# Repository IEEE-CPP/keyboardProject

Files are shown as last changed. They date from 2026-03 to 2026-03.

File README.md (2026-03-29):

# Split Keyboard

A custom split ergonomic keyboard designed with Ergogen and KiCad.

## Keyboard Layout

- **5-column layout**: outer, pinky, ring, middle, index, inner
- **5 rows**: mod, bottom, home, top, num
- **3-thumb keys**: layer, space, extra
- **Column-based wiring** with row diodes

### Features

- Choc hotswap sockets (Kailh Choc low-profile switches)
- Pro Micro microcontroller (ATmega32U4)
- OLED displays (SSD1306, I2C)
- TRRS jack for inter-board communication
- ESD protection on TRRS data lines
- Reset button
- 3D printable case files (STL)

## Files

```
splitKeyboard/
├── ergogen/
│   ├── config.yaml    # Ergogen configuration (layout, PCB definitions)
│   ├── footprints/    # Custom footprint definitions
│   └── output/
│       ├── cases/    # 3D printable case files (STL)
│       └── outlines/ # DXF files for CNC cutting
└── kicad/
    ├── left_board.kicad_pcb   # Left half PCB design
    └── right_board.kicad_pcb  # Right half PCB design
```

## Development Setup

### Manual (recommended)

Install ergogen from https://ergogen.xyz/install/, then generate PCBs:

```bash
ergogen splitKeyboard/ergogen/ --output build/
```

### Nix (optional)

For users with Nix installed:

```bash
nix develop    # provides kicad + ergogen
generate       # runs ergogen (PCB + cases) and organizes output
```

## Design Details

- **Microcontroller**: Pro Micro (5V, 16MHz)
- **Key switches**: Kailh Choc (low-profile)
- **Diodes**: 1N4148 (or similar)
- **OLED**: SSD1306 128x32 I2C
- **Interconnect**: TRRS cable (4-pole)
- **ESD Protection**: TVS diodes (PRTR5V0U2X or similar)

### Pin Mapping

| Column | Pin |
| --- | --- |
| outer  | P21 |
| pinky  | P20 |
| ring | P19 |
| middle | P18 |
| index  | P15 |
| inner  | P14 |
| thumb  | P16 |
| space  | P10 |
| extra  | P9  |

| Row | Pin |
| --- | --- |
| mod | P8  |
| bottom | P7  |
| home | P6  |
| top | P5  |
| num | P4  |

### OLED

- SDA: P2
- SCL: P3

## Building

1. Generate PCB files (see Development Setup above)

2. Open `splitKeyboard/kicad/` in KiCad to generate Gerbers

3. Order PCBs from your preferred manufacturer

4. Solder components:
   - Diodes (observe polarity)
   - Hotswap sockets
   - TRRS jack
   - Reset button
   - OLED display
   - Pro Micro header pins (or socket)

5. Flash firmware using QMK or ZMK

## Firmware

This repository only contains the hardware design. For firmware, use:

- **QMK**: https://github.com/qmk/qmk_firmware
- **ZMK**: https://github.com/zmkfirmware/zmk

## License

GNU General Public License v3. See [LICENSE](LICENSE) for details.

## Credits

- [Ergogen](https://github.com/ergogen/ergogen) - Keyboard layout generator
- [KiCad](https://www.kicad.org/) - PCB design software

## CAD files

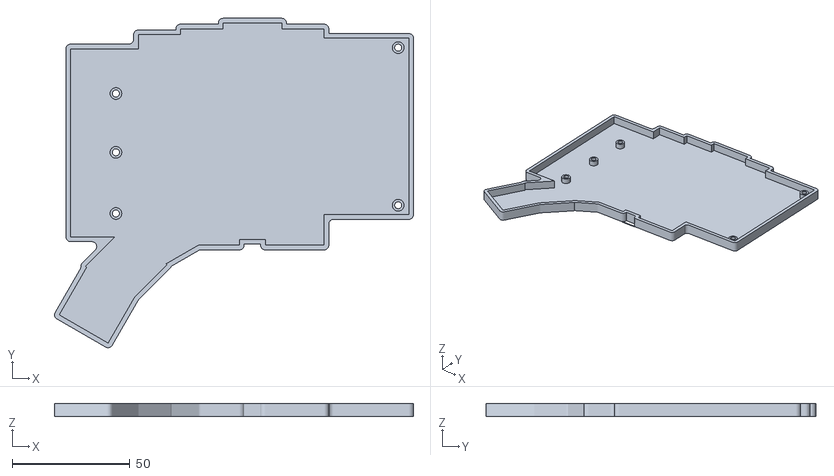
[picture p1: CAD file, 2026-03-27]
splitKeyboard/ergogen/output/cases/right_case.stl
152.6 x 140.1 x 5.60

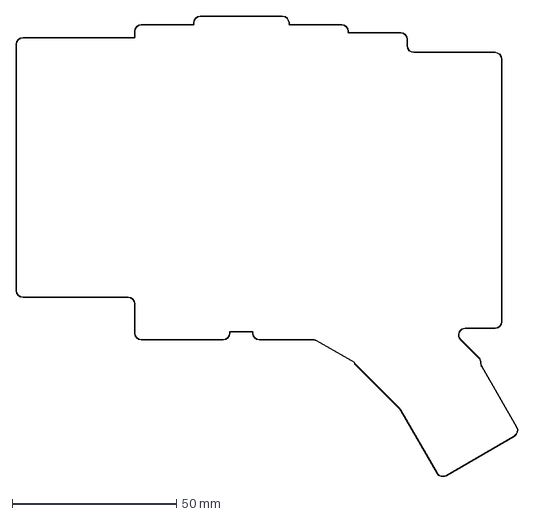
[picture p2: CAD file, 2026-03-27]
splitKeyboard/ergogen/output/outlines/left_xl.dxf
152.9 x 140.2 mm

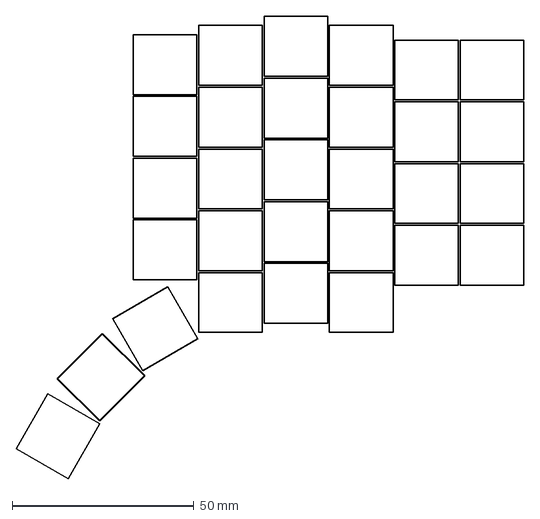
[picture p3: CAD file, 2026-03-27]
splitKeyboard/ergogen/output/outlines/right_keys.dxf
139.7 x 127.2 mm

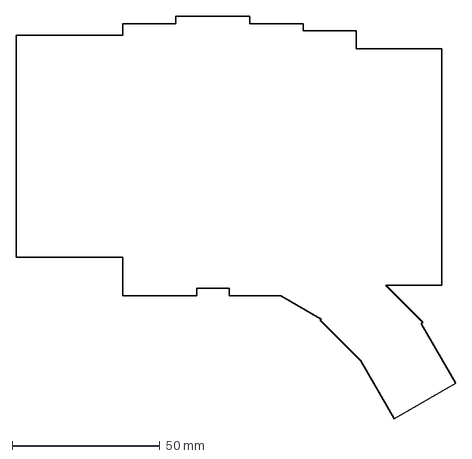
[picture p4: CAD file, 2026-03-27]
splitKeyboard/ergogen/output/outlines/left_raw.dxf
148.6 x 136.1 mm

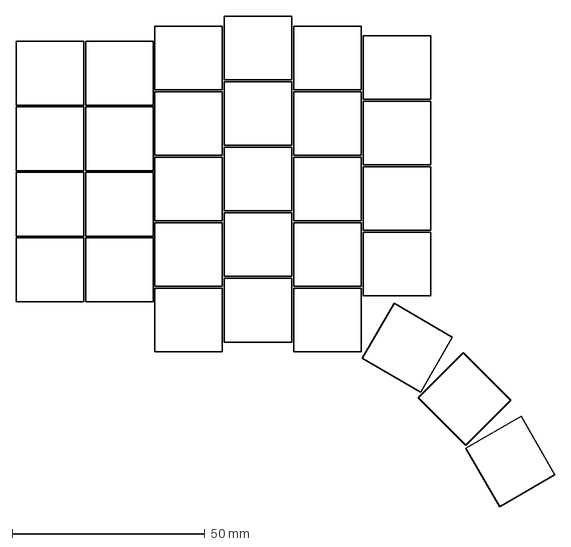
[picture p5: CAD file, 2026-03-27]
splitKeyboard/ergogen/output/outlines/left_keys.dxf
139.7 x 127.2 mm

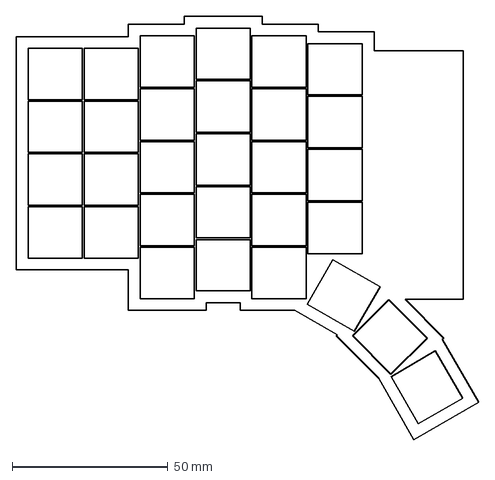
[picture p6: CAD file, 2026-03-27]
splitKeyboard/ergogen/output/outlines/combo_left.dxf
148.6 x 136.1 mm

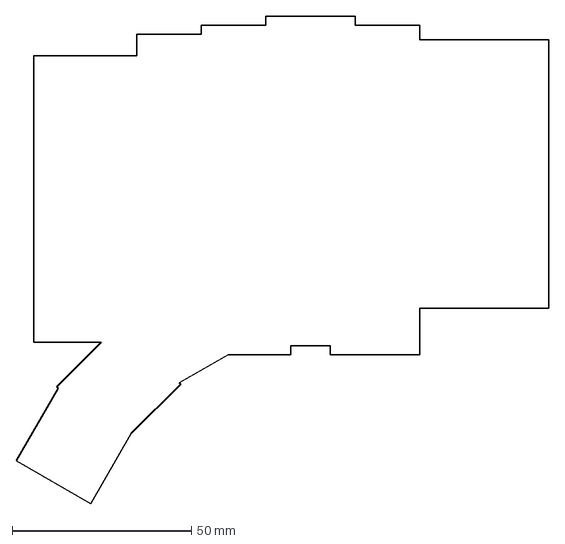
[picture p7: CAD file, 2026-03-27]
splitKeyboard/ergogen/output/outlines/right_raw.dxf
148.6 x 136.1 mm

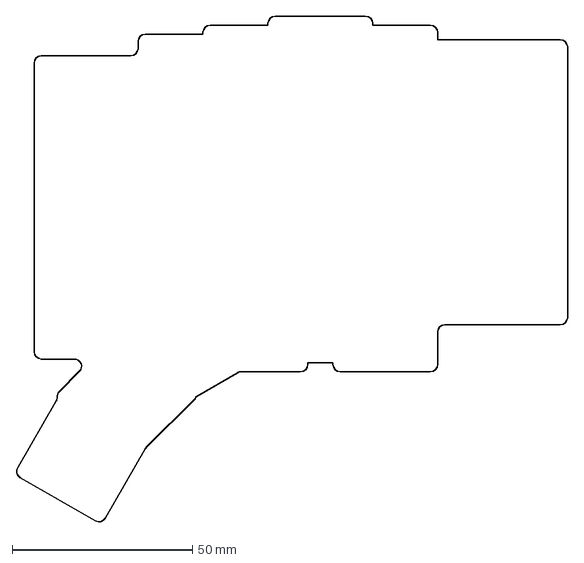
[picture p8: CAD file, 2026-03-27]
splitKeyboard/ergogen/output/outlines/right_xl.dxf
152.7 x 140.4 mm

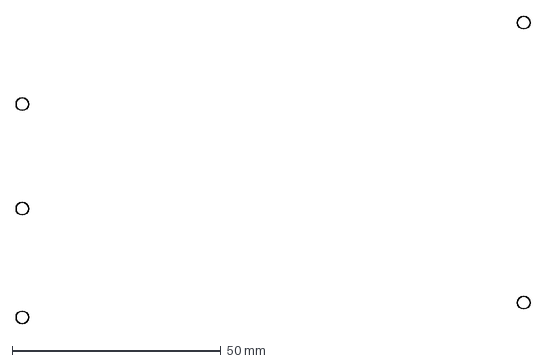
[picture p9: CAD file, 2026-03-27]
splitKeyboard/ergogen/output/outlines/right_mounting.dxf
123.0 x 73.5 mm

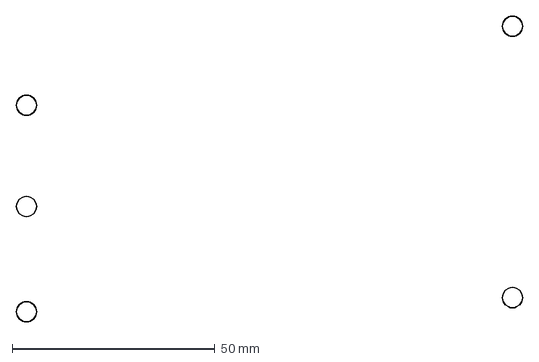
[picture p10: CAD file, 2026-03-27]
splitKeyboard/ergogen/output/outlines/right_standoff.dxf
125.0 x 75.5 mm

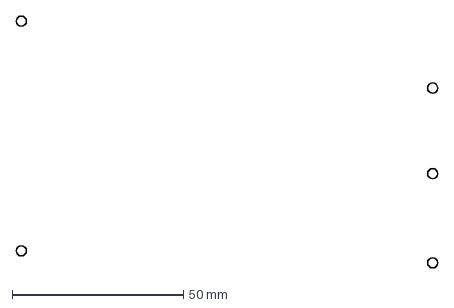
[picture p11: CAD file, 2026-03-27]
splitKeyboard/ergogen/output/outlines/left_mounting.dxf
123.0 x 73.5 mm

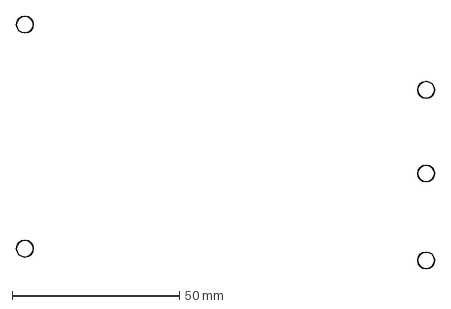
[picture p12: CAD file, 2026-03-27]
splitKeyboard/ergogen/output/outlines/left_standoff.dxf
125.0 x 75.5 mm

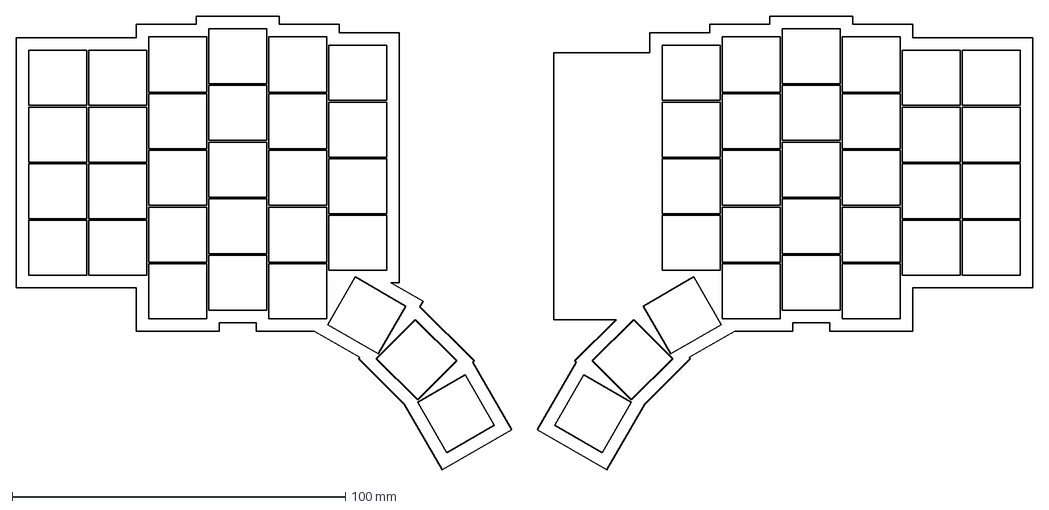
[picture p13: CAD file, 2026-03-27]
splitKeyboard/ergogen/output/outlines/combo_right.dxf
305.0 x 136.1 mm

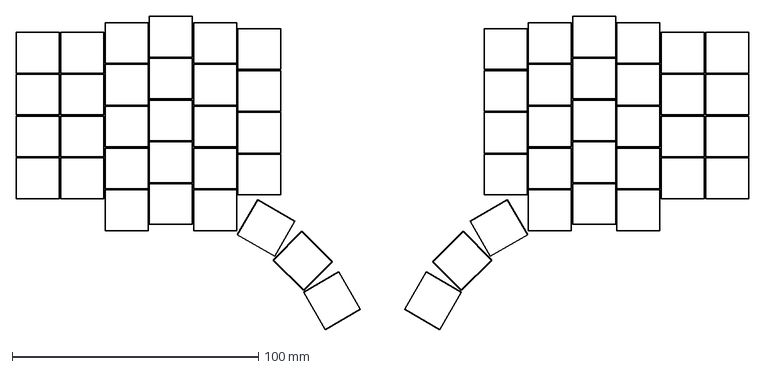
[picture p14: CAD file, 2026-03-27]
splitKeyboard/ergogen/output/outlines/keys.dxf
297.5 x 127.2 mm

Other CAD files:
splitKeyboard/ergogen/output/cases/left_case.stl

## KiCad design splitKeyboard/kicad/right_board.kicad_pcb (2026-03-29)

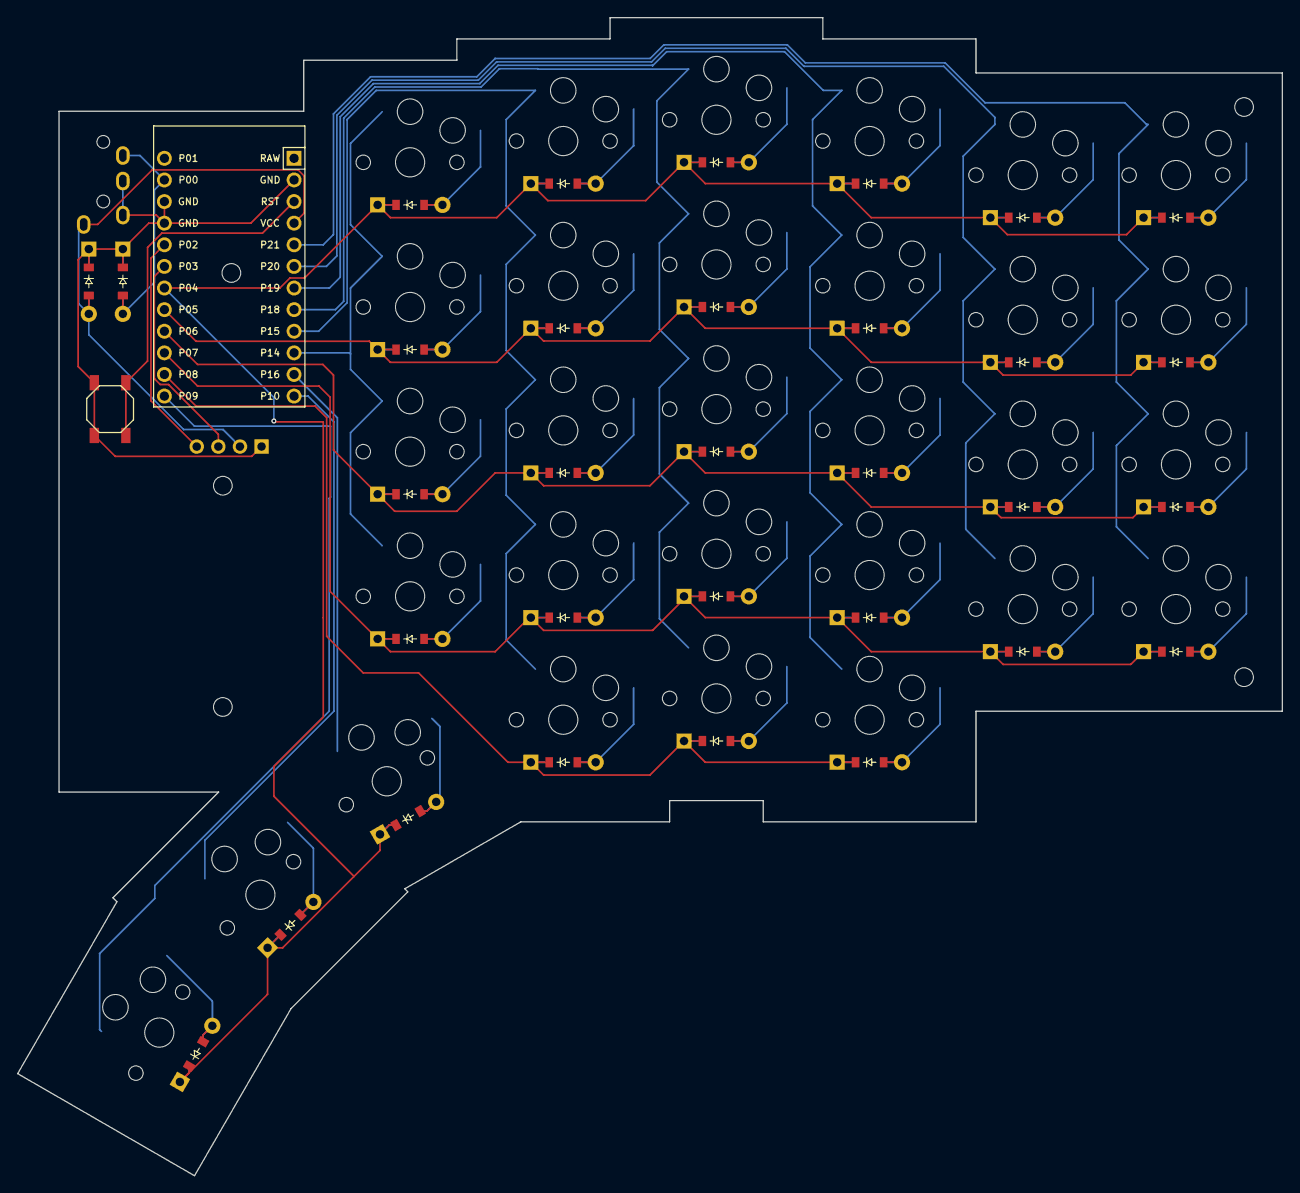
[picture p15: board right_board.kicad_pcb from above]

Board: 2 copper layers, 148.6 x 136.1 mm, 71 parts (0 on the bottom side), 50 nets.

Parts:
B1: SW_TACT_ALPS_SKQGABE010
D1, D2, D3, D4, D5, D6, D7, D8, D9, D10, D11, D12, D13, D14, D15, D16, D17, D18, D19, D20, D21, D22, D23, D24, D25, D26, D27, D28, D29, D30, D31, D32: ComboDiode
MCU1: ProMicro
MH1, MH2, MH3, MH4, MH5: mounting_hole_npth
OLED1: OLED; OLED_headers
S1, S2, S3, S4, S5, S6, S7, S8, S9, S10, S11, S12, S13, S14, S15, S16, S17, S18, S19, S20, S21, S22, S23, S24, S25, S26, S27, S28, S29, S30: PG1350
TRRS1: TRRS-PJ-320A-dual

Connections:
GND: B1.1, D31.1, D32.1, MCU1.2, MCU1.15, MCU1.16, OLED1.1, TRRS1.2, TRRS1.3
P0: D31.2, MCU1.14, TRRS1.4
P2: MCU1.17, OLED1.4
P3: MCU1.18, OLED1.3
P4: D4.1, D8.1, D13.1, D18.1, D23.1, D27.1, D28.1, D29.1, D30.1, MCU1.19
P5: D3.1, D7.1, D12.1, D17.1, D22.1, D26.1, MCU1.20
P6: D2.1, D6.1, D11.1, D16.1, D21.1, D25.1, MCU1.21
P7: D1.1, D5.1, D10.1, D15.1, D20.1, D24.1, MCU1.22
P8: D9.1, D14.1, D19.1, MCU1.23
P9: MCU1.24, S30.1
P10: MCU1.12, S29.1
P14: MCU1.10, S24.1, S25.1, S26.1, S27.1
P15: MCU1.9, S19.1, S20.1, S21.1, S22.1, S23.1
P16: MCU1.11, S28.1
P18: MCU1.8, S14.1, S15.1, S16.1, S17.1, S18.1
P19: MCU1.7, S9.1, S10.1, S11.1, S12.1, S13.1
P20: MCU1.6, S5.1, S6.1, S7.1, S8.1
P21: MCU1.5, S1.1, S2.1, S3.1, S4.1
RST: B1.2, MCU1.3
VCC: D32.2, MCU1.4, OLED1.2, TRRS1.1
mirror_extra_cluster: D30.2, S30.2
mirror_index_bottom: D20.2, S20.2
mirror_index_home: D21.2, S21.2
mirror_index_mod: D19.2, S19.2
mirror_index_num: D23.2, S23.2
mirror_index_top: D22.2, S22.2
mirror_inner_bottom: D24.2, S24.2
mirror_inner_home: D25.2, S25.2
mirror_inner_num: D27.2, S27.2
mirror_inner_top: D26.2, S26.2
mirror_layer_cluster: D28.2, S28.2
mirror_middle_bottom: D15.2, S15.2
mirror_middle_home: D16.2, S16.2
mirror_middle_mod: D14.2, S14.2
mirror_middle_num: D18.2, S18.2
mirror_middle_top: D17.2, S17.2
mirror_outer_bottom: D1.2, S1.2
mirror_outer_home: D2.2, S2.2
mirror_outer_num: D4.2, S4.2
mirror_outer_top: D3.2, S3.2
mirror_pinky_bottom: D5.2, S5.2
mirror_pinky_home: D6.2, S6.2
mirror_pinky_num: D8.2, S8.2
mirror_pinky_top: D7.2, S7.2
mirror_ring_bottom: D10.2, S10.2
mirror_ring_home: D11.2, S11.2
mirror_ring_mod: D9.2, S9.2
mirror_ring_num: D13.2, S13.2
mirror_ring_top: D12.2, S12.2
mirror_space_cluster: D29.2, S29.2

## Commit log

2026-03-26 chore(nix): switched to using dev shell and added ergogen
2026-03-27 chore(nix): added generate command to automate pcb movement
    [combo_left.dxf, combo_right.dxf, keys.dxf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]
2026-03-27 chore(ergogen): added ceoloide's footprints
2026-03-27 feat(board): mounting points and case
    [left_board.kicad_pcb, left_case.stl, left_mounting.dxf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]
2026-03-27 fix: got rid of unnecessary extra side
    [combo_left.dxf, left_board.kicad_pcb, left_keys.dxf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]
2026-03-27 feat(case): increased wall height
    [left_case.stl, right_case.stl]
2026-03-29 feat(left_board): left_board traced
    [left_board.kicad_pcb]
2026-03-29 feat(right_board): right board traced
    [right_board.kicad_pcb]
